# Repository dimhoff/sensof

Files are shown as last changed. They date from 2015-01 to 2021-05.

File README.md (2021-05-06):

# Sensof
Si4010 based wireless sensors(temperature, humidity, etc.) firmware and utilities.

**Project status**: This project is not actively maintained other then some
minor fixes to keep it working for myself.

# Sensof-HT
Sensof-HT is a temperature and humidity sensor that is build using a Si4010 MCU
and a HTU21 sensor.

## Circuit diagram
The Si4010 connects to a HTU21D, Si7020 or compatible sensor through I2C. The
I2C bus is connected to the Si4010 on the following pins:

   GPIO1 = SCL
   GPIO2 = SDA

Voltage level should be between 3.6 - 1.9 Volt. A 3V CR2032 works fine.

Some ready made Si4010 and HTU21D or Si7020 sensor are available on the
internet. These only need to be connected together and connected to a battery.

This repository also contains a custom Sensof-HT PCB. However this is currently
still under development. See hardware/README.md for more information.

## RF communication
The system uses the following modulation/encoding settings:

- Modulation: FSK
- Center Freq: 433.92 MHz
- FSK Deviation: 59 kHz
- Data rate: 9.6 kbits/s
- Encoding: NRZ Only (eg. no encoding)

## Receiver
I use a RFM22B module, which is based on the Si4430 transceiver,
connected to a Raspberry Pi for receiving the signal. The source code of the
receiving program is available in the software/si443x_sensof directory.

I also did some experiments with a SX1231 based module. Which seem to have a
better reception. I don't have any example code for this available in the
source tree.

# Sensof Frame Format
The Sensof frames are compatible with the Si4430/EZRadioPro receiver, and have
the following structure:

    +-----------+-----------+--------------+------------+
    | Preamble  | Sync Word | Enc. Payload | CRC-16-IBM |
    | 13 * 0xaa | 0x2d 0xd4 |   16-byte    |   2-byte   |
    +-----------+-----------+--------------+------------+

The CRC-16 uses the 0x8005 polynomial. The payload is a single AES-128
encrypted block, see [Encrypted Payload].

## Encrypted Payload
The payload is encrypted using AES-128 in ECB mode. To make this secure
against various attacks some mandatory field within the encrypted block have
been defined. The payload is formatted as follows:

    +---------+----------+------------------+
    | Dev. ID | Frame ID | Application data |
    | 4-byte  |  4-byte  |      8-byte      |
    +---------+----------+------------------+

The device ID identifies the source of the message. The Si4010 32-bit uniq
chip ID shall be used for this. The receiver will ignore frames that are from
an unknown source.

The 32-bit frame ID uniquely identifies the frame and allows duplicate frame
detection. The frame ID will be incremented sequentially, starting at 0. The
receiver must only accept frames with a frame ID above the last received frame
ID, and which is a 'reasonable amount higher' than the previous frame ID. See
the [Sensof Security Rational] chapter to get an indication of what a
'reasonable amount higher' means.

The remaining 8 byte can be used for application specific data. It is not
possible to have more or less then 8-byte payload in a single frame. If less
bytes are required the remaining bytes must be set to a known default. For
security reasons the receiver must verify these bytes. If more then 8 bytes
payload are required the payload must be split across multiple frames.

A full explanation of the security model is described below in [Sensof Security
Rational].

## Sensof-HT Frame Payload
The Sensof-HT frames contain the following payload:

 - Temperature(uint16_t): Temperature value as returned by HTU21 IC
 - Humidity(uint16_t): Humidity value as returned by HTU21 IC
 - Padding(uint32_t): '0' padding

See the HTU21 datasheet for the formulas to convert the temperature and
humidity to human readable values.

## SI4430 Compatibility
To receive the frames with the Si4430 receiver the following settings need to
be changed from the default configuration:

 - Header Length = 0
 - Fixed packet length = True
 - Packet length = 16

# Sensof Security Rational
The payload of all Sensof frames are encrypted to guarantee confidentiality and
integrity.

## Confidentiality
The AES algorithm is used with a 128-bit key. Since only a single block is
encrypted the strength of the encryption will be equal to that of the AES
algorithm.

All nodes in a system use the same pre-shared encryption key. This means that
if a single node in the system is suspected to be compromised the whole system
needs to be re-keyed.

## Integrity
The system depends on the avalanche effect of the AES block cipher protect
it integrity.

This means that if an adversary changes a single bit in the cipher text, that
the plain text changes completely and in an to the adversary unpredictable
manner.

By embedding known values into the encrypted blocks the receiver can verify
the decrypted data by checking if the known values are correct. In case of the
Sensof frames the device ID and frame ID are used for this. The change that an
adversary generates a frame that is accepted by the receiver would (probably)
be (somewhere in the order of):

    P = (N / 2^32) * (W / 2^32)

Where:
 N = Number of known nodes
 W = Size of accepted frame ID window

Of course any structure in the remaining 8 byte of payload will contribute to
this integrity protection. Therefor it is suggested to set any unused bytes to
'0', or any other fixed value, and verify these bytes on the receiver.

### Replay attack
To protect against replay attacks every frame has a 32-bit counter embedded.
The receiver must only accept frames with a frame ID above the last received
frame ID, and which is not more then a reasonable amount higher than the
previous frame ID.

In this case reasonable is the maximum amount of packets that one can expect to
be lost during normal operation.

It is essential that the receiver is initialized with the correct replay
counter at startup.  Just accepting the replay counter of the first received
frame as the current replay counter is not suggested. This allows an adversary
to replay a previously recorded stream of frames.

A suggested way is too let the receiver (periodically) store the current replay
counters per device and time to non-volatile storage. Upon restart of the
receiver these values should be read from storage and based on this the last
frame ID per device should be determined.
 In case of senders that send with a fix periodic interval this calculation can
be pretty accurate. For non-periodic senders other measures need to be taken
depending on the required security level.

If a sender losses its frame ID there are multiple possibilities:

 1. Reload node with expected frame ID based on the receiver's state
 2. Change the Device ID of the node
 3. Change the encryption key for the whole system

### Delay attack
In a delay attack the adversary provides the receiver with outdated
information. For example in a burglar alarm delaying the measurements of the
sensors for an hour would allow an adversary to break into the building with
the alarm only triggering after an hour.

To preform this attack the adversary would need to be able to prevent frames of
a node to reach the receiver, and record and replay those frames. This would
work if the receiver only relies on the frame ID from the frames to determine
the expected frame ID.

To prevent this attack for nodes that send packets with a fixed period the
receiver can protect against this by taking into account the frame interval,
current time and time of the last received frame to calculate what the expected
frame ID should be. Of course this system must leave some room for in accuracy
in the sending interval. But in general this should greatly reduce the attack
surface(Sorry, not going to prove statement this here...).

For nodes that do not have a periodic interval of sending frames the current
system does **NOT** offer any protection. If this is required an alternative
system where a time value is used instead of a frame ID can be considered.

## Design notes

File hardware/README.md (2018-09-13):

Sensof HT hardware
==================
Currently there are two PCB designs for the Sensof HT nodes:

 - v1: With on board 50 Ohm ceremic antenna
 - v2: With on board printed trace loop antenna

Sensof HT v1 PCB (0002-00-00)
=============================
This is an experimental PCB for the Sensof HT nodes. Main features of this PCB
are:

 - Uses a Ceramic 50 Ohm antenna + matching network
 - Has extensions connectors to connect to GPIO/I2C

The Ceramic antenna was chosen to see if it had a better range then a
differential loop antenna. It also allows for a smaller PCB.

The extension headers would allow other uses then just the Humidity/Temperature
sensor. And make it easier to experiment/develop with these modules.

Issues
-------
The following issues are found with the first prototype board(tag:
'hardware/0002-00-00')

### Range
The range of the is very limited. Apparently the antenna matching isn't optimal.

Replacing the antenna with a SMA connector, and then hooking the PCB up to a
HackRF through an attenuator, allowed for some simple tests.

This showed the output power to be relative high compared to a RFM60S. But the
power level is not very constant when sending a long pulse.

Doing a frequency sweep shows the power level is stable in the 300-400 MHz
range. I would have expected a spike around 434 MHz, like in AN369 "SI4010
Antenna Interface and Matching Network Guide"

### Assembly
The matching network makes assembly complicated and requires the device to be
reflow soldered.

### Price
The amount of quality components needed for antenna matching and the antenna it
self are relative expensive.

Sensof HT v2 PCB (0003-00-00)
=============================
This is an experimental PCB for the Sensof HT nodes. Main features of this PCB
are:

 - Use a differential loop antenna
 - Have a properly placed test pads to build test bed

The differential loop antenna is cheap and is easy in assembly.

To allow testing and firmware loading access is required to some of the Si4010
pins. In this design test pads are chosen. This eliminates the cost and
assembly of an extra connector that is only used during production. By placing
the test pads at a fixed pitch it should be easy to build a test bed with test
pins and a protoboard.

Issues
------
No serious issues were found with the first prototype board(tag:
'hardware/0003-00-00').

Range is comparable with the RFM60s based nodes I used before.

Only minor point is that the test points are spaced an 2.5 mm instead of 2.54
mm(0.1") but this within the acceptable margins.

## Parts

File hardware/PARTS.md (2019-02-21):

# Sensof HT v2
## Part Numbering
Part numbers are made up as follows:

  0003-pp-rr

Where:
 - 0003: Project number
 - pp: Part number
 - rr: Part revision

## Parts
These are the assigned partnumbers:

 - 00: Sensof HT v2 PCB Assembled
 - 01: Top layer solder stencil for Sensof HT v2 PCB
 - 02: Bottom layer solder stencil for Sensof HT v2 PCB
 - 03: Sensof HT v2 PCB Bare
 - 10: Casing Assembled
 - 11: Casing - Top
 - 12: Casing - Bottom
 - 80: Sensof HT v2 assembled device

## Project Breakdown Structure
Below is a structured breakdown of the project components. The identifier
before the '=' sign is the reference of a component within the sub assembly.
So what you see here is like a tree of BOM's.

 - SENSOF = Sensof HT v2 assembled device (0003-80)
   - PCB = PCB assembled (0003-00)
     - PCB = PCB Bare (0003-03)
     - * = See BOM schematics
   - CASING = Casing Assembled (0003-10)
     - TOP = Casing - Top (0003-11)
     - BOT = Casing - Bottom (0003-12)
     - SCREW = Screw ST2.2x6.5
   - BAT = CR2032 battery

# Sensof HT v1
Project number: 0002

Parts:
 - 00: Sensof HT v1 PCB Assembled
 - 01: Top layer solder stencil for Sensof HT v1 PCB
 - 02: *reserved for bottom layer stencil*
 - 03: Sensof HT v1 PCB Bare

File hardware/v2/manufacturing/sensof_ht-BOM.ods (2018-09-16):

Reference | Value | Requirements | Footprint | Manufacturer | Mfr. No | Mouser No | Mouser | Alternative | Original
BT1 | CR2032 |  | silabs_cr2032:silabs_cr2032 | Linx Technologies | BAT-HLD-001 | 712-BAT-HLD-001 | https://nl.mouser.com/ProductDetail/Linx-Technologies/BAT-HLD-001
C1 | 2.7pF | ±5%; C0G (based on 4010-DKMX-434_BOM.xls) | silabs_0402:C_0402 | Murata | GJM1555C1H2R7BB01D | 81-GJM1555C1H2R7BB01 | https://nl.mouser.com/ProductDetail/81-GJM1555C1H2R7BB01
C2 | N.F. |  | Capacitors_SMD:C_0603 | - | - | - | -
C3 | 2.2uF |  | Capacitors_SMD:C_0603 | Taiyo Yuden | LMK107BJ225KAHT | 963-LMK107BJ225KAHT | https://nl.mouser.com/ProductDetail/963-LMK107BJ225KAHT
C4 | 1nF |  | Capacitors_SMD:C_0603 | KEMET | C0603C102J5RACTU | 80-C0603C102J5R | https://nl.mouser.com/ProductDetail/80-C0603C102J5R
C5 | 270pF |  | Capacitors_SMD:C_0603 | Yageo | CC0603JRX7R9BB271 | 603-CC603JRX7R9BB271 | https://nl.mouser.com/ProductDetail/603-CC603JRX7R9BB271
C6 | 100nF |  | Capacitors_SMD:C_0603 | Yageo | CC0603KRX7R6BB104 | 603-CC603KRX7R6BB104 | https://nl.mouser.com/ProductDetail/603-CC603KRX7R6BB104
L1 | 220nH | Coilcraft 0402HP-220NX_LU | silabs_0402:C_0402 | Murata | LQW15CNR22J10D | 81-LQW15CNR22J10D | https://nl.mouser.com/ProductDetail/Murata-Electronics/LQW15CNR22J10D |  | https://nl.mouser.com/ProductDetail/Coilcraft/0402HPH-R22XJLU
R1 | 10k |  | Resistors_SMD:R_0603 | Yageo | RE0603FRE0710KL | 603-RE0603FRE0710KL | https://nl.mouser.com/ProductDetail/Yageo/RE0603FRE0710KL
R2 | 10k |  | Resistors_SMD:R_0603 | Yageo | RE0603FRE0710KL | 603-RE0603FRE0710KL | https://nl.mouser.com/ProductDetail/Yageo/RE0603FRE0710KL
U1 | Si4010-GS |  | Housings_SOIC:SOIC-14_3.9x8.7mm_Pitch1.27mm | Silicon Labs | SI4010-C2-GS | 634-SI4010-C2-GS | https://nl.mouser.com/ProductDetail/Silicon-Labs/SI4010-C2-GS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
U2 | HTU21D/Si7020 |  | Housings_DFN_QFN:DFN-6-1EP_3x3mm_Pitch0.95mm | TE Connectivity | HTU21DF | 824-HPP845E131R5 | https://nl.mouser.com/ProductDetail/634-SI7020-A20-GM1 | https://nl.mouser.com/ProductDetail/Measurement-Specialties/HPP845E131R5

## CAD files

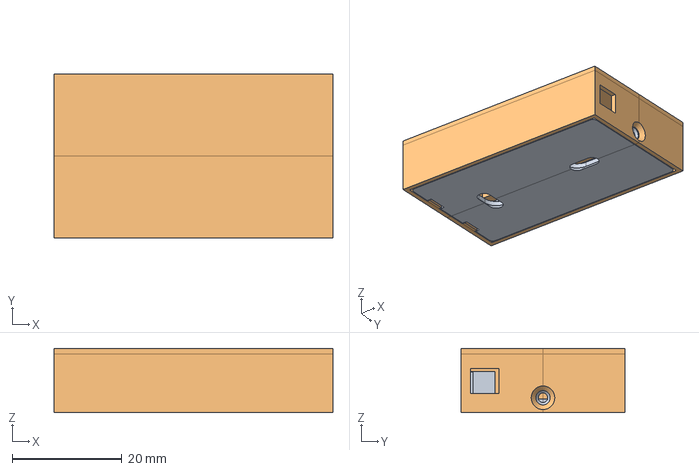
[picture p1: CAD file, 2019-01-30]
casing/sensof_casing.fcstd
50.9 x 29.9 x 11.7 mm
BottomPlateWithCountersink
TopCasingWith3DPrintingSupports

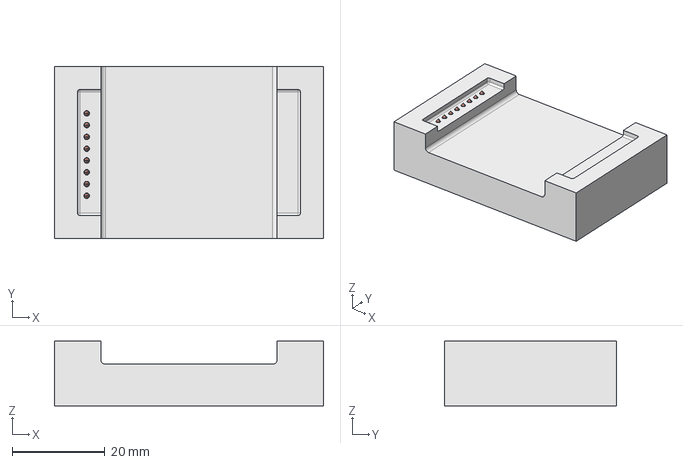
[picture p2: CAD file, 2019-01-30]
hardware/v2/programmer/programmer.fcstd
58.0 x 37.0 x 14.0 mm

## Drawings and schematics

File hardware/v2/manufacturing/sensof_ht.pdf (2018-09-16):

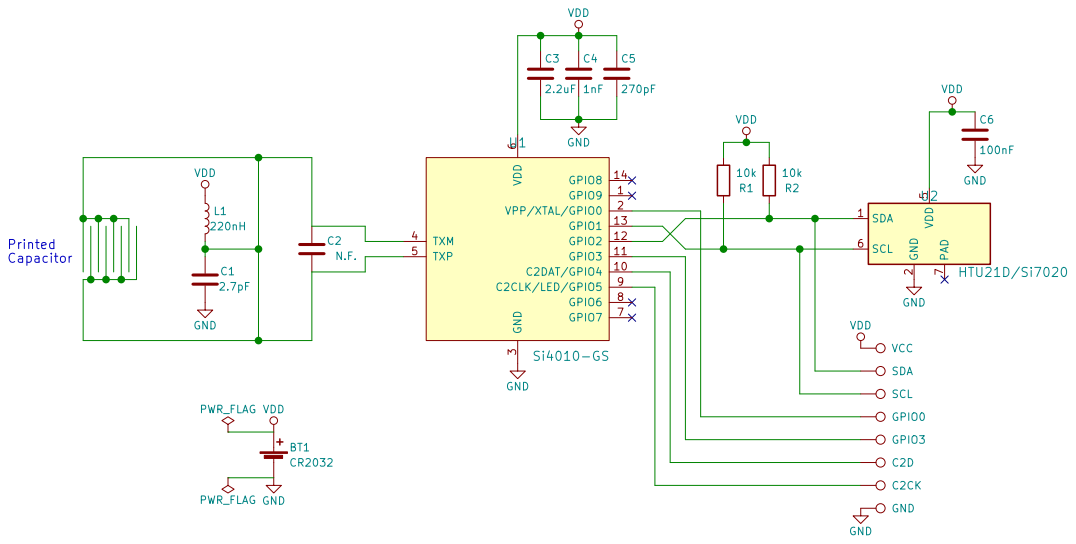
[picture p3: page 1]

License: BSD-3-Clause Project: 0003 C1

File: sensof_ht.sch Sheet: / Copyright (c) 2018, David Imhoff <dimhoff.devel@gmail.com>

Id: 1/1 Title: Sensof HT v2

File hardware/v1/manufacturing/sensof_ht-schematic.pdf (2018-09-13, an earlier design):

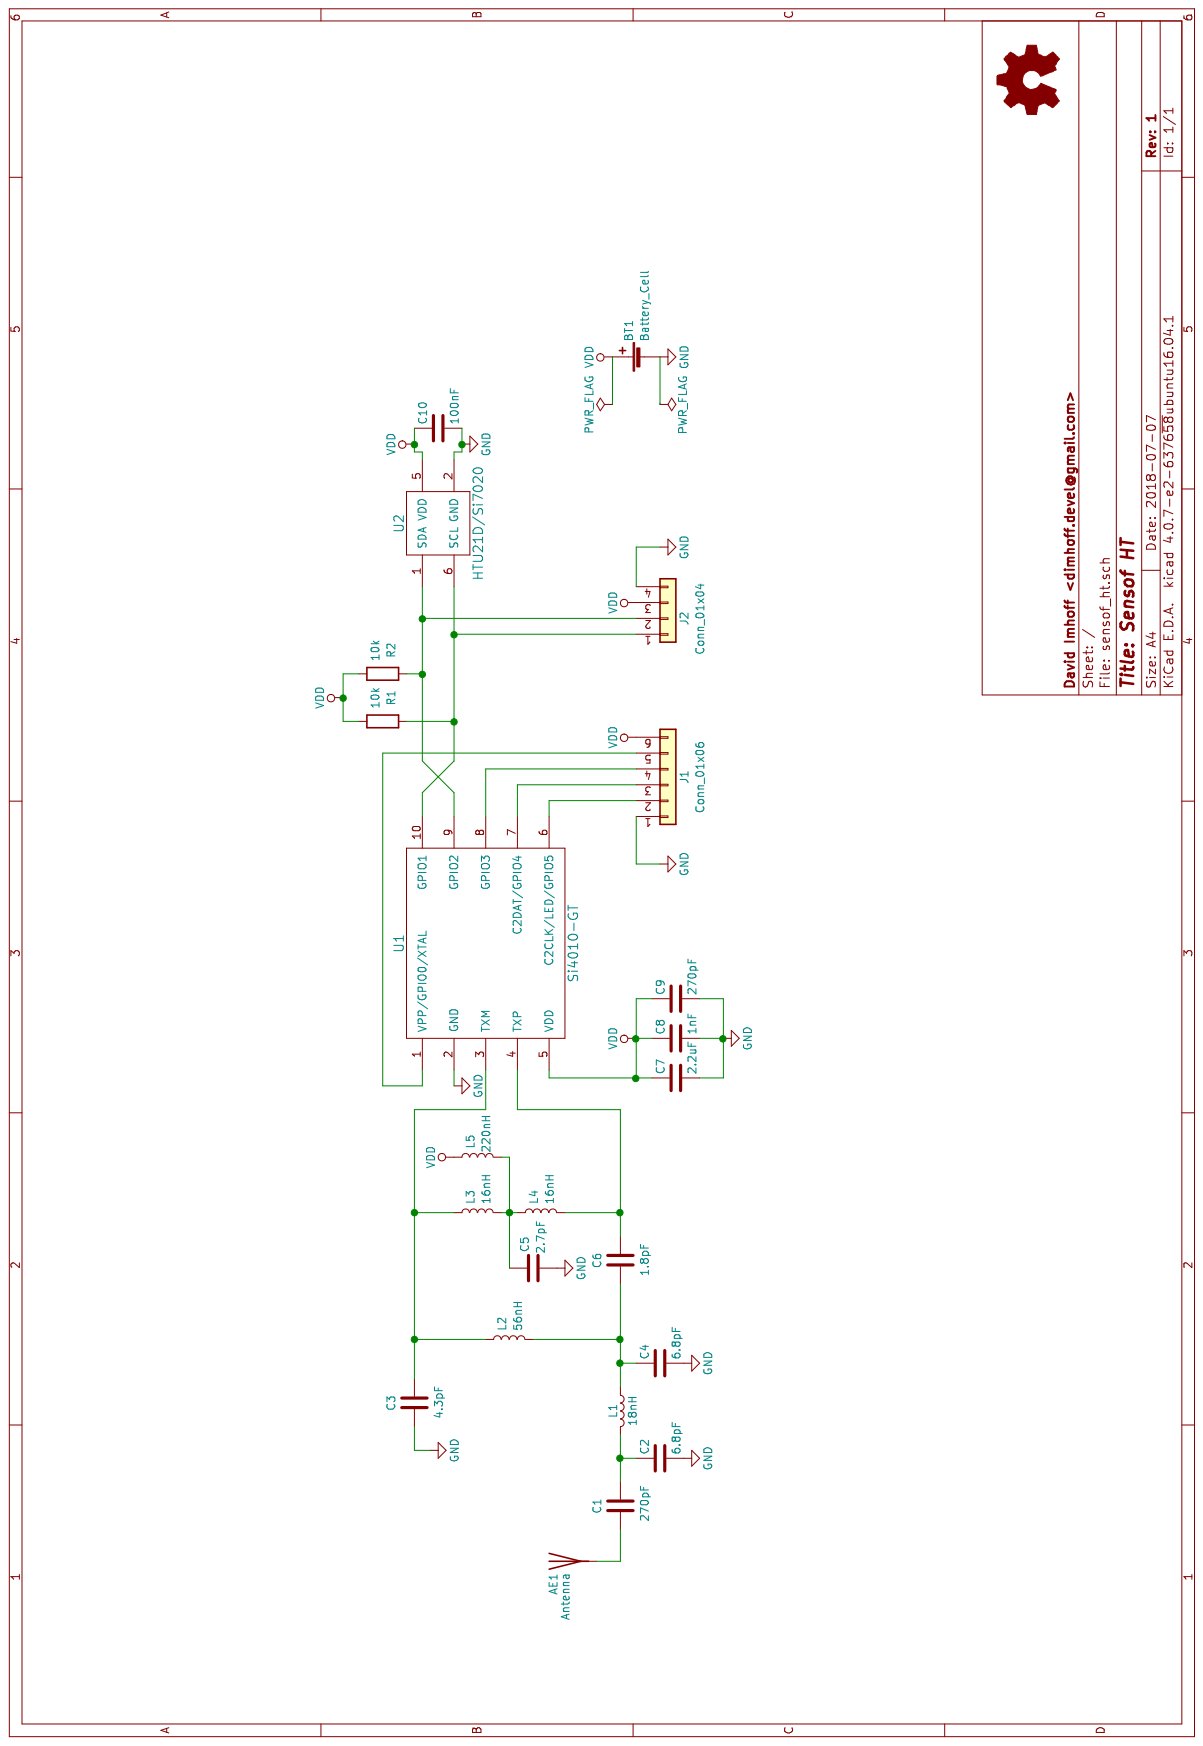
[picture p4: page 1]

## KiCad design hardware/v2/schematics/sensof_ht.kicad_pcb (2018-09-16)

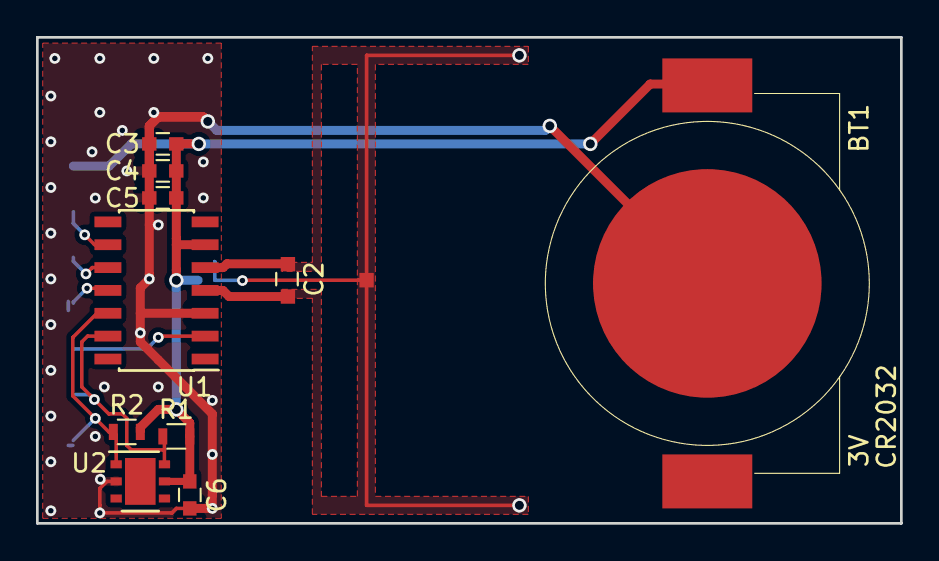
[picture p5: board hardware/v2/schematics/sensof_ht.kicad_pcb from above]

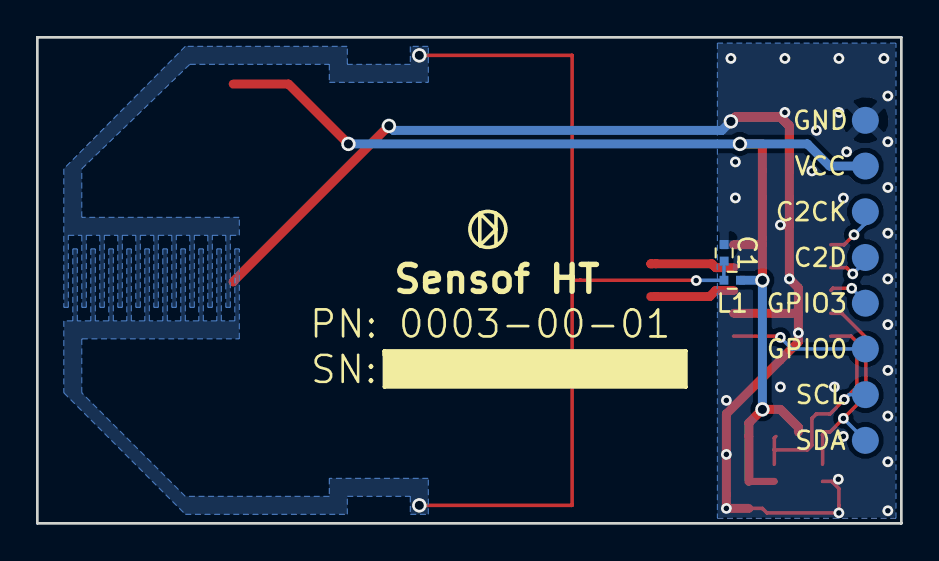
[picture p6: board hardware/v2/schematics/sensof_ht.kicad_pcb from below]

Board: 2 copper layers, 48.0 x 27.0 mm, 20 parts (10 on the bottom side), 9 nets.

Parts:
BT1: CR2032; silabs_cr2032
C1: 2.7pF; C_0402
C2: N.F.; C_0603
C3: 2.2uF; C_0603
C4: 1nF; C_0603
C5: 270pF; C_0603
C6: 100nF; C_0603
L1: 220nH; C_0402
R1, R2: 10k; R_0603
TP1: VCC; Measurement_Point_Round-SMD-Pad_Small-Labeled
TP2: SDA; Measurement_Point_Round-SMD-Pad_Small-Labeled
TP3: SCL; Measurement_Point_Round-SMD-Pad_Small-Labeled
TP4: GPIO0; Measurement_Point_Round-SMD-Pad_Small-Labeled
TP5: GPIO3; Measurement_Point_Round-SMD-Pad_Small-Labeled
TP6: C2D; Measurement_Point_Round-SMD-Pad_Small-Labeled
TP7: C2CK; Measurement_Point_Round-SMD-Pad_Small-Labeled
TP8: GND; Measurement_Point_Round-SMD-Pad_Small-Labeled
U1: Si4010-GT; SOIC-14_3.9x8.7mm_Pitch1.27mm
U2: HTU21D/Si7020; DFN-6-1EP_3x3mm_Pitch0.95mm

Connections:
GND: BT1.2, C1.1, C3.2, C4.2, C5.2, C6.2, TP8.1, U1.3, U2.2
unnamed: C1.2, C2.1, C2.2, L1.2, U1.4, U1.5
unnamed: R1.2, TP3.1, U1.13, U2.6
unnamed: R2.2, TP2.1, U1.12, U2.1
unnamed: TP4.1, U1.2
unnamed: TP5.1, U1.11
unnamed: TP6.1, U1.10
unnamed: TP7.1, U1.9
VDD: BT1.1, C3.1, C4.1, C5.1, C6.1, L1.1, R1.1, R2.1, TP1.1, U1.6, U2.5

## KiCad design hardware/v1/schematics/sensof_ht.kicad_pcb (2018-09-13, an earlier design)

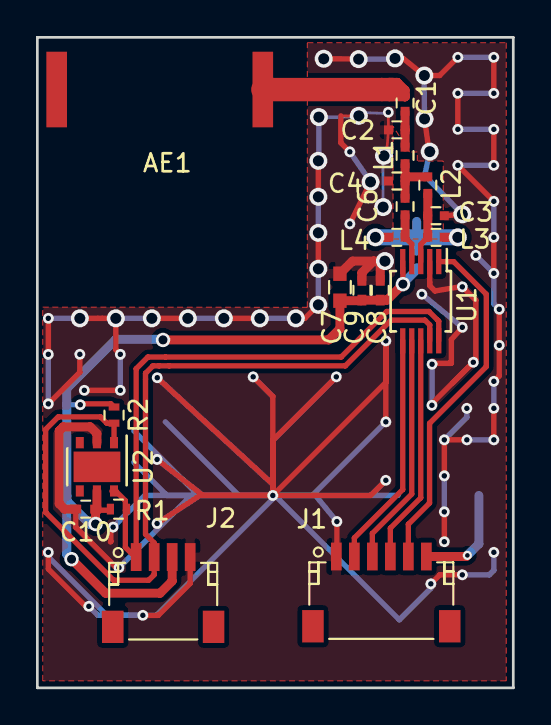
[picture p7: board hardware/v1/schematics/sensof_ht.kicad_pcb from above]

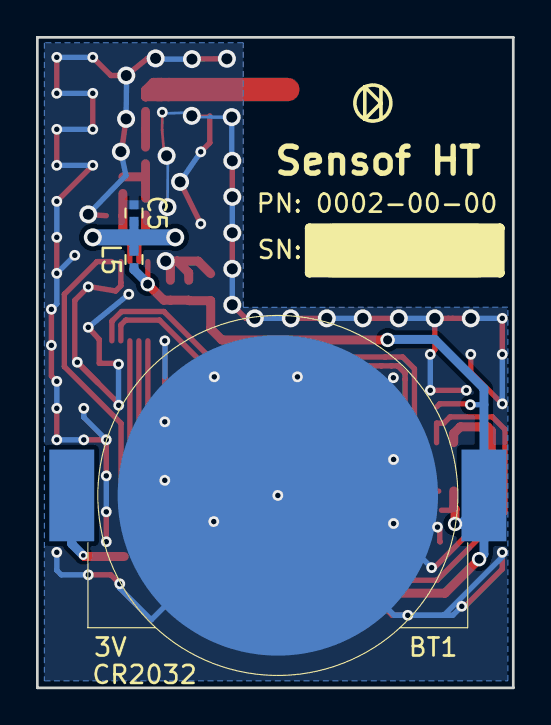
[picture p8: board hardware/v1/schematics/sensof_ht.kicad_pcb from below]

Board: 2 copper layers, 26.4 x 36.1 mm, 23 parts (3 on the bottom side), 14 nets.

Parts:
AE1: Antenna; ACAG1204-433-T
BT1: Battery_Cell; Linx_BAT-HLD-001
C1, C9: 270pF; C_0402
C2, C4: 6.8pF; C_0402
C3: 4.3pF; C_0402
C5: 2.7pF; C_0402
C6: 1.8pF; C_0402
C7: 2.2uF; C_0603
C8: 1nF; C_0402
C10: 100nF; C_0402
J1: Conn_01x06; JST_SH_SM06B-SRSS-TB_06x1.00mm_Angled
J2: Conn_01x04; JST_SH_SM04B-SRSS-TB_04x1.00mm_Angled
L1: 18nH; C_0402
L2: 56nH; C_0402
L3, L4: 16nH; C_0402
L5: 220nH; C_0402
R1, R2: 10k; R_0402
U1: Si4010-GT; MSOP-10_3x3mm_Pitch0.5mm
U2: HTU21D; DFN-6-1EP_3x3mm_Pitch0.95mm

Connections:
GND: BT1.2, C2.2, C3.2, C4.2, C5.1, C7.2, C8.2, C9.2, C10.2, J1.1, J2.4, U1.2, U2.2
unnamed: AE1.1, C1.2
unnamed: C1.1, C2.1, L1.2
unnamed: C3.1, L2.1, L3.1, U1.3
unnamed: C4.1, C6.2, L1.1, L2.2
unnamed: C5.2, L3.2, L4.1, L5.2
unnamed: C6.1, L4.2, U1.4
unnamed: J1.2, U1.6
unnamed: J1.3, U1.7
unnamed: J1.4, U1.8
unnamed: J1.5, U1.1
unnamed: J2.1, R1.2, U1.10, U2.6
unnamed: J2.2, R2.2, U1.9, U2.1
VDD: BT1.1, C7.1, C8.1, C9.1, C10.1, J1.6, J2.3, L5.1, R1.1, R2.1, U1.5, U2.5

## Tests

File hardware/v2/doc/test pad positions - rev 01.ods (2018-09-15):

 | Corner | GND | VCC | C2CK | C2D | GPIO3 | GPIO0 | GPIO1 | GPIO2
Absolute X | 124 | 126 | 126 | 126 | 126 | 126 | 126 | 126 | 126
Absolute Y | 78.95 | 83.56 | 86.1 | 88.64 | 91.18 | 93.72 | 96.26 | 98.8 | 101.34
Relative X | 0 | 2 | 2 | 2 | 2 | 2 | 2 | 2 | 2
Relative Y | 0 | 4.61 | 7.15 | 9.69 | 12.23 | 14.77 | 17.31 | 19.85 | 22.39

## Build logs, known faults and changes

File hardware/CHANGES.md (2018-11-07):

# 0002-00: Sensof HT v1 PCB
## 0002-00-00
 * Initial PCB

## 0002-00-01
 * Change GND fill zone around matching network to be closer to SiLabs reference design
 * Added 'SN' field in silk screen for writing down serial number
 * Upgraded to KiCad 5.0
 * Switched to di_kicad_library repository for symbols & footprints

# 0002-01: Top layer solder stencil
## 0002-01-00
 * Initial stencil for 0002-00-00 PCB

# 0003-00: Sensof HT v2 PCB
## 0003-00-00
 * Initial PCB

## 0003-00-01
 * Upgraded to KiCad 5.0
 * Switched to di_kicad_library repository for symbols & footprints
 * Change test pad positions

# 0003-01: Top layer solder stencil
## 0003-01-00
 * Initial top stencil for 0003-00-00 PCB

# 0003-02: Bottom layer solder stencil
## 0003-02-00
 * Initial bottom stencil for 0003-00-00 PCB

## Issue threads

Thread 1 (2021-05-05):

Make it work on 27Mhz

xromansx, 2021-05-05:
On main page I didn't find the frequency this device should work and if it's configurable can it work on 27Mhz ?

dimhoff, 2021-05-06:
No it doesn't and will never work on 27 MHz.

xromansx, 2021-05-06:
SI4010  frequency rande 27–960 MHz why it can't be used on 27Mhz.

dimhoff, 2021-05-13:
Apparte from any physical hardware limitations, because its not in the scope of this project.

If you really want the have Sensof sensors on 27 MHz. Then please send my your contact details so I can prepare a quote on how much development would cost you.

Closed 2021-05-06.

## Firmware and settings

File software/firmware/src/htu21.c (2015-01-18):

#include "htu21.h"
#include "soft_i2c.h"
#include "crc.h"
#include "timing_si4010.h"

#define HTU21_MEASURE_TEMP         0xE3 // Trigger Temperature Measurement (Hold master)
#define HTU21_MEASURE_HUM          0xE5 // Trigger Humidity Measurement (Hold master)
#define HTU21_MEASURE_TEMP_NO_HOLD 0xF3 // Trigger Temperature Measurement (No Hold master)
#define HTU21_MEASURE_HUM_NO_HOLD  0xF5 // Trigger Humidity Measurement (No Hold master)
#define HTU21_WRITE_REG            0xE6 // Write user register
#define HTU21_READ_REG             0xE7 // Read user register 
#define HTU21_SOFT_RESET           0xFE // Soft Reset

#define HTU21_MAX_RETRIES          5

static uint8_t _htu21_measure(bool temperature, uint16_t *val)
{
	unsigned char b;
	uint8_t crc;

	crc = 0;

	i2c_flags |= I2C_START;

	i2c_write_byte(0x80);
	if (! (i2c_flags & I2C_ACK)) goto fatal;
	if (i2c_flags & I2C_BERR) goto fatal;

	if (temperature) {
		i2c_write_byte(HTU21_MEASURE_TEMP);
	} else {
		i2c_write_byte(HTU21_MEASURE_HUM);
	}
	if (! (i2c_flags & I2C_ACK)) goto fatal;
	if (i2c_flags & I2C_BERR) goto fatal;

	i2c_flags |= I2C_START;

	i2c_write_byte(0x81);
	if (! (i2c_flags & I2C_ACK)) goto fatal;
	if (i2c_flags & I2C_BERR) goto fatal;

	// Data (MSB)
	b = i2c_read_byte();
	if (i2c_flags & I2C_BERR) goto fatal;
	crc = crc8(crc, b);
	((uint8_t *) val)[0] = b; // same as: *val = b << 8; but much less instructions

	// Data (LSB) | Status
	b = i2c_read_byte();
	if (i2c_flags & I2C_BERR) goto fatal;
	crc = crc8(crc, b);
	((uint8_t *) val)[1] = b; // same as: *val = *val | b; but much less instructions

	// CRC-8
	i2c_flags |= I2C_LASTRD;
	b = i2c_read_byte();
	if (i2c_flags & I2C_BERR) goto fatal;

	i2c_stop();

	return (b != crc);

fatal:
	i2c_stop();
	return 1;
}

void htu21_init()
{
	i2c_init();
}

bool htu21_read(uint16_t *temp, uint16_t *hum)
{
	uint8_t i;
	uint8_t res;

	//
	// soft reset
	//
	i2c_flags |= I2C_START;

	i2c_write_byte(0x80);
	if (! (i2c_flags & I2C_ACK)) goto fatal;
	if (i2c_flags & I2C_BERR) goto fatal;

	i2c_write_byte(HTU21_SOFT_RESET);
	if (! (i2c_flags & I2C_ACK)) goto fatal;
	if (i2c_flags & I2C_BERR) goto fatal;

	i2c_stop();

	wait_10us(250);
	wait_10us(250);
	wait_10us(250);
	wait_10us(250);
	wait_10us(250);
	wait_10us(250);

/*This was only for testing?
	//
	// Read status/config register
	//
	i2c_flags |= I2C_START;

	i2c_write_byte(0x80);
	if (! (i2c_flags & I2C_ACK)) goto fatal;
	if (i2c_flags & I2C_BERR) goto fatal;

	i2c_write_byte(HTU21_READ_REG);
	if (! (i2c_flags & I2C_ACK)) goto fatal;
	if (i2c_flags & I2C_BERR) goto fatal;

	i2c_flags |= I2C_START;

	i2c_write_byte(0x81);
	if (! (i2c_flags & I2C_ACK)) goto fatal;
	if (i2c_flags & I2C_BERR) goto fatal;

	i2c_flags |= I2C_LASTRD;
	b = i2c_read_byte();
	if (i2c_flags & I2C_BERR) goto fatal;

	i2c_stop();
*/

	//
	// Measure Temperature
	//
	i = 0;
	do {
		res = _htu21_measure(true, temp);
	} while (res != 0 && i++ < HTU21_MAX_RETRIES);

	if (res != 0) {
		return 1;
	}

	//
	// Measure Humidity
	//
	i = 0;
	do {
		res = _htu21_measure(false, hum);
	} while (res != 0 && i++ < HTU21_MAX_RETRIES);
	
	if (res != 0) {
		return 1;
	}

	return 0;

fatal:
	i2c_stop();
	return 1;
}

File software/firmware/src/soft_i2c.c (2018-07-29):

#include "soft_i2c.h"

#include <si4010.h>

#ifdef HAVE_STDBOOL
 #include <stdbool.h>
#else
 #define bool bit
 #define true 1
 #define false 0
#endif
#include "timing_si4010.h"

#define SCL	GPIO1
#define SDA	GPIO2

unsigned char i2c_flags = 0;

void i2c_init()
{
	SCL = 1;
	SDA = 1;
	i2c_flags = 0;
}

static void i2c_delay()
{
	wait_10us(1);
}

static void i2c_start()
{
	unsigned int i;
	if (i2c_flags & I2C_STARTED) {
		SDA = 1;
		i2c_delay();
		SCL = 1;

		// clock stretching
		i = 0xFFFF;
		while (SCL == 0 && --i != 0) {
			i2c_delay();
		}
		if (i == 0) {
			i2c_flags |= I2C_TIMEOUT;
			return;
		}

		i2c_delay();
	}

	SDA = 0;
	SDA = 0; // dummy write to make sure next read returns correct value
	if (SDA != 0) {
		i2c_flags |= I2C_ARB;
		return;
	}
	i2c_delay();
	SCL = 0;

	i2c_flags &= (~I2C_START);
	i2c_flags |= I2C_STARTED;
}

void i2c_stop()
{
	SCL = 1;
	i2c_delay();
	SDA = 1;

	i2c_flags &= (~(I2C_STOP | I2C_STARTED));
}

static void i2c_write_bit(bool v)
{
	unsigned int i;

	SDA = v;
	i2c_delay();
	SCL = 1;

	// clock stretching
	i = 0xFFFF;
	while (SCL == 0 && --i != 0) i2c_delay();
	if (i == 0) {
		i2c_flags |= I2C_TIMEOUT;
		return;
	}

	// arbitration lost
	if (SDA != v) {
		i2c_flags |= I2C_ARB;
		return;
	}

	i2c_delay();
	SCL = 0;
}

static bool i2c_read_bit()
{
	unsigned int i;
	bool retval;

	SDA = 1;
	i2c_delay();
	SCL = 1;

	// clock stretching
	i = 0xFFFF;
	while (SCL == 0 && --i != 0) i2c_delay();
	if (i == 0) {
		i2c_flags |= I2C_TIMEOUT;
		return 1;
	}

	retval = SDA;

	i2c_delay();
	SCL = 0;

	return retval;
}

void i2c_write_byte(unsigned char b)
{
	unsigned char i;

	if (i2c_flags & I2C_START) {
		i2c_start();
		if (i2c_flags & I2C_BERR) {
			return;
		}
	}

	i=8;
	while (i--) {
		i2c_write_bit((b & 0x80) != 0);
		if (i2c_flags & I2C_BERR) {
			return;
		}
		b <<= 1;
	}

	if (i2c_read_bit()) {
		i2c_flags &= (~I2C_ACK);
	} else {
		i2c_flags |= I2C_ACK;
	}
	if (i2c_flags & I2C_BERR) {
		return;
	}

	if (i2c_flags & I2C_STOP) {
		i2c_stop();
	}
}

unsigned char i2c_read_byte()
{
	unsigned char i;
	unsigned char b = 0;

	i=8;
	while (i--) {
		b <<= 1;
		b |= i2c_read_bit() ? 1 : 0;
		if (i2c_flags & I2C_BERR) {
			return 0;
		}
	}

	i2c_write_bit((i2c_flags & I2C_LASTRD) != 0);
	i2c_flags &= (~I2C_LASTRD);
	if (i2c_flags & I2C_BERR) {
		return 0;
	}

	if (i2c_flags & I2C_STOP) {
		i2c_stop();
	}

	return b;
}

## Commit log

2015-04-15 Remove Header and Packet length from frame
2015-04-15 Increase packet counter to 32-bit
    Also created byte accessor to write/read packet counter to/from HVRAM.
    This save a lot in code size.
    Also don't increase packet counter if failed to read
    temperature/humidity.
2015-07-17 Add compile option to store replay counter in MTP
    By storing the packet counter in MTP the replay protection will also
    work across full power downs. This way we can change batteries without
    having to rekey or manually set the replay counter in HVRAM.
2018-07-29 FW: Switch I2C pins to GPIO1/GPIO2
    Also disabled GPIO Matrix mode for this to work.
2018-08-17 FW: Update PA settings for Sensof HT (0002-00-00) board
    This also sets the output level to max.
2018-09-08 FW: add PA parameters for v2 PCB and lower level for v1
    For the v1 board use the max. that the calculation sheet allows.
2018-09-13 HW: Change fill zones and via's around matching network + add SN field
    Changed the fill zones and via's to much closer resemble the Silabs
    reference design. This also moves the C7/C8/C9 components.
    Also added a silkscreen box where the Serial number can be written down.
    [sensof_ht.kicad_pcb]
2018-09-13 Added Sensof-HT PCB
    [sensof_ht-BOM.ods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]
2018-09-13 HW: Updated V1 schematic to KiCad 5.0
    [sensof_ht.sch]
2018-09-13 Si443x: Add correct register settings and calculation sheet
    This register settings uses the current packet format, with crc and
    without header.
    [Si443x-Register-Settings_RevB1_Sensof.ods]
2018-09-13 HW: update schematic information
    Just some textual update to schematic information fields.
    The current 0002-00-01 schematic has revision '01'. While the 0002-00-00
    schematic had revision '1'. This was a mistake, it should have been
    '00'. So '1' != '01'...
    [sensof_ht.sch]
2018-09-13 HW: Update V1 schematic to use di_kicad_library and global library
    Import the di_kicad_library repository and swith the V1 schematic to use
    it. Also replace symbol for HTU21D with Si7020-A20 symbol from KiCad
    global library.
    [sensof_ht.sch]
2018-09-13 Update symbol/footprints library
    Some small non functional updates to shared KiCad Library.
    Also updates the PCB board information with copyright etc.
    [sensof_ht.kicad_pcb, sensof_ht.sch]
2018-09-13 Add KiCad gitignore for hardware directory
2018-09-13 HW: move Current PCB to V1 directory
    [sensof_ht-BOM.ods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]
2018-09-13 DOC: move inductor selection sheet into BOM sheet
    [sensof_ht-BOM.ods]
2018-09-13 si443x_sensof: Fine tune baud to calculated value.
    The wanted baud rate is 9600 but due to clock dividers the actual baud
    rate is 9590 baud. This was determined by the Si4010 calculation sheet.
    [Si443x-Register-Settings_RevB1_Sensof.ods]
2018-09-13 HW: PCBv2 Upgraded to KiCad 5.0 and switch to shared component library
    [sensof_ht.sch]
2018-09-13 HW: Set Si7020 as primary choice for sensor, and HTU21DF as alternative
    Switch this around since I prefer the Si7020.
    [sensof_ht-BOM.ods]
2018-09-13 HW: remove temporary BOM export files
2018-09-13 HW: Added Sensof HT v2 board
    New board with printed PCB antenna based on the 4010-DKMX-434 reference
    design.
    [sensof_ht-BOM.ods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]
2018-09-13 HW: Add readme for the different PCB designs
2018-09-15 PCBv2: Updated Test pad possitions
    Also removed a lot of ground traces that where there for the stitching
    via's. But it seems KiCad 5 is smart enough to recognize via's in a fill
    zone as belonging to that zone.
    [sensof_ht.kicad_pcb]
2018-09-15 PCBv2: add documentation of test pad possitions
    [test pad positions - rev 01.ods]
2018-09-16 PCBv2: Cleanup unused libraries
    These components are now in KiCad or in di_kicad_library repository.
2018-09-16 PCBv2: Add part numbers to schematic
    Added part numbers from BOM to schematic.
    [sensof_ht.sch]
2018-09-16 PCBv2: generated manufacturing files for PCB 0003-00-01
    [sensof_ht-B.Cu.gbr, sensof_ht-B.Mask.gbr, sensof_ht-B.Paste.gbr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]
2018-09-16 PCBv2: Add part requirements to schematic
    [sensof_ht.sch]
2018-09-16 PCBv2: Extended BOM with exact part specifications
    [sensof_ht-BOM.ods]
2019-01-30 Added casing design for V2 PCB
    [sensof_casing.fcstd]
2019-01-30 Added Programming/Test fixture for V2 PCB
    [programmer.fcstd]
2019-02-20 Reorder directories and add new .gitignore
    Bring it more inline with my other projects structure.
    [Si443x-Register-Settings_RevB1_Sensof.ods]
2019-02-20 HW: Added BOM suggestions to schematic for V1 hardware
    Add Manufacturer, mfr. no, mouser no fields to schematic.
    [sensof_ht.sch]
2019-02-21 HW: extend part number list with casing and bare PCB
2019-02-21 HW: Change part suggestions to the once I actually used in the prototype
    [sensof_ht.sch]
